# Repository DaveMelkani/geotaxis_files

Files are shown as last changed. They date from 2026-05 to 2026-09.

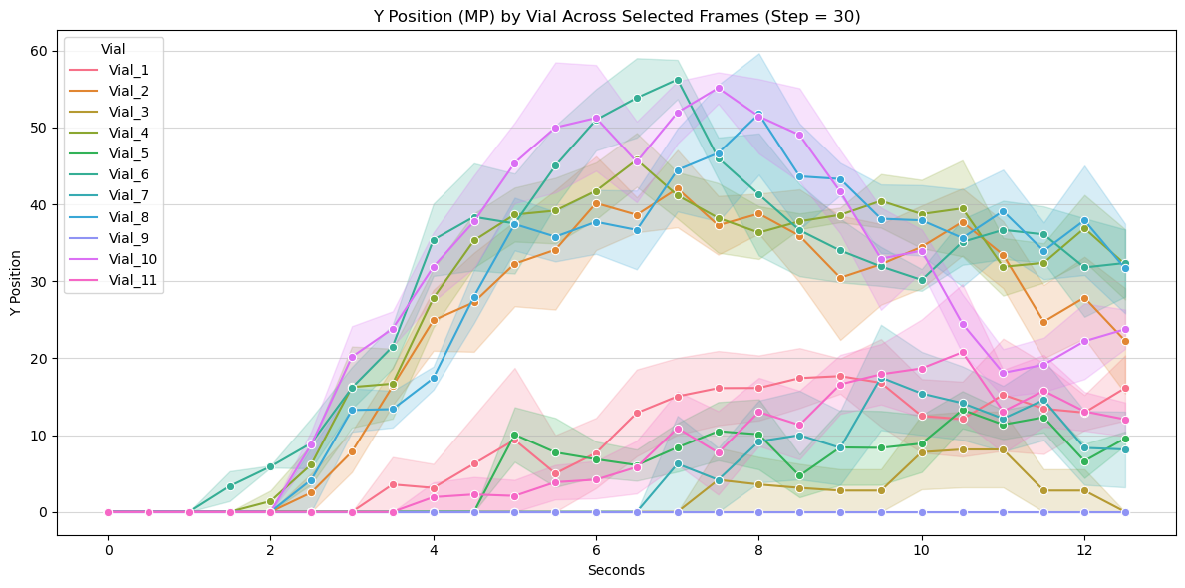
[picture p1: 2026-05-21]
Glaz_PolG_RNAi/Dev_Set2_GLAZ_POLG1_7wk_June_03_2025/percentage_MP_plot.png

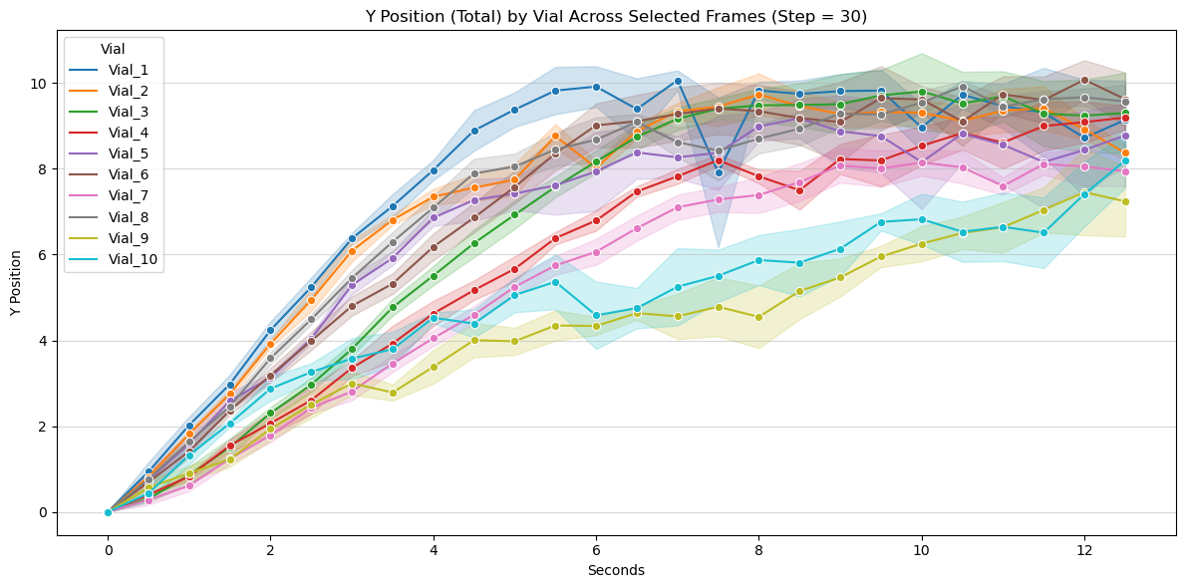
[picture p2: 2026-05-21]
Glaz_PolG_RNAi/Dev_Set2_GLAZ_POLG1_3wk_Jan_27_2024/position_Total_plot.png

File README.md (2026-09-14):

# Geotaxis Files

A hardware–software pipeline for fully automated, high-throughput negative geotaxis (climbing) assays in Drosophila melanogaster. The system pairs a 3D-printed, motorized 12-vial recording rig with an end-to-end Python/PyTorch analysis pipeline that converts raw video directly into time-resolved climbing metrics and statistical comparisons across genotypes, sexes, and ages, with no manual scoring or frame-by-frame human intervention required.

## System Overview & Purpose

Traditional negative geotaxis scoring requires a researcher to manually pause video at a fixed endpoint, draw a reference line, and tally the fraction of flies above it which is a process that is slow, low-resolution (a single data point per vial per trial), and subject to observer bias.

This pipeline replaces that workflow with continuous, population-level video tracking: raw H.264 recordings from the accompanying Raspberry Pi–based hardware rig are automatically converted, split into individual climbing trials, and analyzed frame-by-frame to extract climbing position, velocity, and zone occupancy for every vial, fully automatically, then statistically compared across user-specified genotype and age groups.

## Hardware 

The recording apparatus (STL files in main_stl_files_and_folders/) consists of:
- A custom 3D-printed 12-position vial holder and third-class-lever tapping mechanism, driven by a DC motor via an L298N motor driver module
- A Raspberry Pi 4B, controlling both the tapping motor (via GPIO) and video capture
- A Raspberry Pi HQ Camera (12.3 MP Sony IMX477 sensor) with a 6 mm CS-mount lens, recording at 60 fps, 1280×720
- A fixed lamp light source, positioned to eliminate glare and standardize illumination for background subtraction

A Python control script (run on the Pi) automatically executes four tap–climb cycles per recording: each cycle taps the vial rack (grounding the flies), then records a 15-second quiescent climbing window, for a total of four independent climbing trials per video file.

Full assembly instructions, GPIO pin assignments, and a complete bill of materials are provided in the manuscript's Supplementary Information.

## Core Features & Capabilities

**Vial detection**

- Custom-trained Faster R-CNN (ResNet-50 + Feature Pyramid Network) object detector, trained from scratch (no pretrained weights) on 1,140 annotated frames / 13,680 vial instances
- Inference filtered at confidence ≥ 0.85, with left-to-right spatial sorting of detected vials
- Achieves mean IoU > 0.95 against manual annotations on held-out validation frames

**Fly detection and zone classification**

- Per-pixel-max background subtraction (red-channel isolation) computed independently for each trimmed video
- Connected-component analysis to extract fly centroids per frame, filtered by area
- Each centroid assigned to a vial and classified into Low / Middle / High Performer (LP / MP / HP) vertical zones based on y-position, enabling continuous zone-occupancy tracking (not just an endpoint threshold)
- Population-level (not identity-preserving) tracking: all fly positions within a vial are averaged at each frame, avoiding identity-switching errors that arise from occlusion during climbing

**Video processing**

- Automated H.264 → MP4 conversion (ffmpeg, lossless quality settings)
- Automatic trial splitting into four 15-second clips via OpenCV MOG2 motion detection and SciPy peak/inactivity detection; no manual round definition required

**Statistical analysis**

- Linear Mixed-Effects (LME) models (Statsmodels, REML) with fixed effects for genotype, time, and their interaction, and random intercepts/slopes per vial to properly account for autocorrelated, repeated-measures data
- Harmonic Mean p-value (HMP) combination across correlated LME terms per genotype comparison
- Time-resolved Mann–Whitney U tests with BH-FDR corrections at each discrete timepoint, visualized as –log₁₀(q) significance heatmaps
- Peak-position summary bar plots with embedded significance annotations and replicate counts (N)

**Automation and batch processing**
- Iterates automatically over an arbitrary number of experiment/video subfolders
- Skips subfolders that have already been fully processed, enabling safe resumption of interrupted runs
- Aggregates results into sex-specific ("Output Males" / "Output Females") summary CSVs and plots across all processed videos

## Execution Pipeline Walkthrough

The pipeline runs in three sequential stages, orchestrated by MAIN_geotaxis.py (or interactively via gt_full_process.ipynb), and is also available as a standalone GUI executable for Windows, macOS, and Ubuntu Linux (no Python installation required).

### Stage 1: Recording

Assemble the hardware rig, load vials into the 12-position holder, and record via the on-device Python script. Each recording folder must contain the raw .h264 video and a geotaxis_metadata.csv file (columns: Vial_Num, Genotype, Sex, n), named identically to the video file. Recording folders are organized under a single top-level experiment directory (see Repository Structure below).

### Stage 2: Processing

For each unprocessed video subfolder, the pipeline automatically:
1. Converts the .h264 file to .mp4
2. Splits the video into four 15-second trimmed climbing trials via motion detection
3. Detects and spatially sorts vials with the Faster R-CNN model
4. Tracks fly centroids per frame and classifies them into LP/MP/HP zones
5. Subsamples to 2 Hz and converts pixel/frame units to centimeters/seconds
6. Writes per-trial CSVs and diagnostic plots

### Stage 3: Aggregation and Statistics

- Aggregates all per-trial outputs into wide-form, sex-specific summary tables (position, velocity, LP%, MP%, HP%) across replicates
- Computes climbing velocity as the numerical gradient of mean position over time
- Fits LME models and runs time-resolved Mann–Whitney U tests for a user-specified control genotype vs. one or more comparison genotypes, over a user-defined time window
- Outputs annotated trajectory plots, peak-position bar plots, and significance heatmaps

## Quantified Behavioral & Kinematic Metrics

| Metric | Unit | Description |
| --- | --- | --- |
| Position | cm | Mean climbing height across all tracked flies in a vial at each timepoint, calibrated from pixel coordinates via chamber height (17 cm / 720 px). |
| Velocity | cm/s | 	Instantaneous climbing speed, computed as the numerical gradient of mean position over time. |
| Low Performer (LP) | %  | Percentage of tracked flies in the lowest vertical zone of the vial at each timepoint. |
| Middle Performer (MP) | % | Percentage of tracked flies in the middle vertical zone at each timepoint. |
| High Performer (HP) | % | Percentage of tracked flies in the highest vertical zone at each timepoint. |
---

## Repository Structure
 
```
geotaxis_files/
├── MAIN_geotaxis.py            # Entry point for the full pipeline
├── gt_full_process.ipynb       # Interactive Jupyter notebook walkthrough
├── gt_process.py               # Core per-experiment processing logic
├── gt_data_agg.py              # Aggregation of processed data across experiments
├── statistical_analysis.py     # Mann-Whitney U tests and output generation
├── vial_network.py             # Vial detection/tracking network utilities
├── video_processor.py          # Frame extraction and fly position tracking
├── video_converter.py          # H.264 → MP4 conversion helper
├── file_installs.txt           # Required package list
├── main_stl_files_and_folders/ # 3D-printable hardware components
├── Glaz_PolG_RNAi/             # Experiment set: Glaz × PolG RNAi crosses
└── W1118_CLKOut/               # Experiment set: W1118 × CLK-out crosses
```

## File Formats

**Input:** .h264 video files (60 fps, 1280×720) with an accompanying geotaxis_metadata.csv per subfolder.

**Per-video output:** vial-position CSVs, per-trim fly-tracking CSVs, and diagnostic plots.

**Per-experiment output:** ten aggregated CSVs (5 metrics × 2 sexes), written to Output Males / Output Females subdirectories, plus PNG trajectory/bar/heatmap plots. All CSV outputs are compatible with GraphPad Prism, R, and Excel.

**Hardware:** 3D-printable .stl files for the vial holder, tapping arm, camera mount, and base frame (main_stl_files_and_folders/).

---

## Requirements

Python 3.8+ with: PyTorch (v2.3.1+cu121), torchvision, OpenCV, NumPy, Pandas, SciPy, Statsmodels, Matplotlib, Seaborn. NVIDIA CUDA 12.1 is recommended for vial detection but the pipeline automatically falls back to CPU execution if no compatible GPU is available. Standalone executables (no Python required) are available for Windows, macOS, and Ubuntu Linux.

## Citation

If you use this repository or platform in your research, please cite:

[1] Melkani D., Harnwal N., Desai S., Patel D., Melkani G. (year) Design and Implementation of an Automated Drosophila Locomotor Assay Using Computer Vision Tracking, submitted<br>

```
@article{Melkani2026Geotaxis,
  title     = {Design and Implementation of an Automated Drosophila Locomotor Assay Using Computer Vision Tracking},
  author    = {Melkani, Dave and Harnwal, Neelaksh and Desai, Shubhankar and Patel, Dev and Melkani, Girish C.},
  journal   = {Department of Pathology, University of Alabama at Birmingham},
  year      = {2026}
}
```

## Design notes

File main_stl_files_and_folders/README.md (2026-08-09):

# 3D-Printed Geotaxis Assay Device: STL File README

All STL files required to reproduce the device described in the associated manuscript are organized into the subfolders listed below. Print settings for each component are provided in the [Print Settings](#print-settings) section. Non-printed hardware requirements are listed in the [Bill of Materials](#bill-of-materials) section.

---

## Table of Contents

1. [Device Overview](#device-overview)
2. [How the Mechanism Works](#how-the-mechanism-works)
3. [File Structure](#file-structure)
4. [STL Files by Assembly](#stl-files-by-assembly)
   - [1. Curved Vial Holder](#1-curved-vial-holder)
   - [2. Arm / Middle Attachment](#2-arm--middle-attachment)
   - [3. Connecting Rod (Coupler)](#3-connecting-rod-coupler)
   - [4. Crank (Input Link)](#4-crank-input-link)
   - [5. Motor / Drive](#5-motor--drive)
   - [6. Base Frame](#6-base-frame)
   - [7. Cable Management Box](#7-cable-management-box)
5. [Assembly Order](#assembly-order)
6. [Print Settings](#print-settings)
7. [Bill of Materials](#bill-of-materials)

---

## Device Overview

This device automates the *Drosophila* geotaxis assay. It holds a set of fly vials in a curved arm, mechanically taps them to the bottom, and allows the flies to climb upward against gravity. A motorized crank-rocker mechanism converts continuous motor rotation into a repeating lift-and-tap oscillation of the vial arm at a consistent, user-controlled frequency.

The full mechanical system is 3D printed with the exception of two steel guide rods, bearings, screws, and the electric motor/gearbox unit.

---

## How the Mechanism Works

The device is a **crank-rocker four-bar linkage**. The key components and their roles are:

- **Base Frame** — The rigid black structure sitting on the bench, including two horizontal parallel steel rods. These rods connect the motor assembly to the pivot stand, keeping everything in alignment.
- **Motor & Gearbox** — An electric motor drives a 3D-printed gear pair to reduce rotational speed and increase torque.
- **Crank (Input Link)** — Attached directly to the gearbox output shaft. Rotates continuously in a full 360° circle.
- **Connecting Rod (Coupler)** — Links the crank's outer pin to the underside of the lever arm. An adjustable metal sleeve on this piece allows fine-tuning of the stroke length and resting height.
- **Lever Arm (Rocker)** — The long articulated arm spanning the top of the device. Pushed upward from below by the connecting rod and pinned at its right end to the fulcrum.
- **Pivot / Fulcrum** — The A-frame structure at the right end of the device. Houses a bearing and pin that act as the stationary hinge for the lever arm.
- **Vial Holder (End Effector)** — The curved vial holder at the left end of the lever arm. Swings upward when the crank pushes the arm, then drops back down to tap the flies to the bottom of the vials.

**Sequence of motion:**

1. The motor turns on, driving the gearbox and forcing the crank to rotate.
2. The crank's outer pin moves in a circle; the connecting rod transmits this motion upward.
3. The connecting rod pushes up on the mid-point of the lever arm.
4. Because the right end of the lever arm is fixed to the pivot point, the left end (carrying the vial holder) swings upward in an arc.
5. As the crank continues past the top of its rotation, it pulls the connecting rod down, which pulls the lever arm and vial holder back to the starting position, thus tapping the flies to the bottom.
6. This cycle repeats continuously at a frequency set by the motor speed.

---

## File Structure

```
main_files_and_folders_so_far/
├── curved_vial_holder/
│   ├── Curved_Vialholder.stl
│   ├── Curved_TopCover.stl
│   └── Gept_Arm_Backplate.stl
├── middle_parts_attach_holder/
│   ├── Vial_Holder_Connector.stl
│   ├── Piston_Push_Mid_link.stl
│   ├── Arm_Rotation_Bearing_Mount.stl
│   ├── Arm_Length_Body.stl
│   └── GeoT_Fulcram.stl
├── connecting_rod/
│   ├── Top_Bearing_TO_Cylinder_Connector.stl
│   ├── Top_Push_Cylinder.stl
│   └── Bottom_Bearing_Rod_Adapter(Piston).stl
├── crank_input_link/
│   ├── Crank_Hand.stl
│   ├── CrankStand_BottomBrace.stl
│   └── Crank_Stand.stl
├── motor_drive/
│   ├── Big_Motor_Faceplate.stl
│   ├── Big_motorSeat_brace.stl
│   ├── Big_motorSeat.stl
│   ├── Motor_Brace.stl
│   └── GeoT_gear_crank.stl
├── base_frame/
│   └── GeoT_Base_Fulcram_Mount.stl
│   └── GeoT_Base_Motor_Drive_Mount.stl
└── cable_management_box/
    ├── drivermount.stl
    └── drivermount_top.stl
```

---

## STL Files by Assembly

### 1. Curved Vial Holder
**Subfolder:** `curved_vial_holder/`

This is the end effector — the outermost component of the device. It holds the fly vials and is the part that swings upward and taps downward during the assay.

| File | Description |
|---|---|
| `Curved_Vialholder.stl` | Main curved arm with 12 vial slots arranged in a fan. **Print with supports.** |
| `Curved_TopCover.stl` | Cover that clips over the 12 vial openings to prevent vials from jumping out when the arm drops. |
| `Gept_Arm_Backplate.stl` | Backplate that bridges the vial holder to the arm sleeve (`Vial_Holder_Connector.stl`). Acts as the structural interface between the holder and the rest of the lever arm. |

---

### 2. Arm / Middle Attachment
**Subfolder:** `middle_parts_attach_holder/`

These parts form the lever arm — the long articulated arm that spans the top of the device. It is pinned at the right end (at the fulcrum) and free to swing at the left end where the vial holder attaches.

| File | Description |
|---|---|
| `Vial_Holder_Connector.stl` | Sleeve that fits over the lever arm body. Connects to `Gept_Arm_Backplate.stl` at one end and `Piston_Push_Mid-link.stl` at the other. |
| `Piston_Push_Mid-link.stl` | Central connector piece. Interfaces between the arm sleeve, the lever arm body, and the crank-rocker mechanism below. |
| `Arm_Rotation_Bearing_Mount.stl` | The body-end of the lever arm that connects to the fulcrum (`GeoT_Fulcram.stl`). |
| `Arm_Length_Body.stl` | Internal insert that provides stiffness, length and bearing surfaces at the pivot end of the arm. |
| `GeoT_Fulcram.stl` | The A-frame fulcrum stand on the right side of the device. This is the stationary anchor point — the lever arm rotates around a pin housed here. Two steel guide rods pass through its base to connect it rigidly to the motor assembly. |

---

### 3. Connecting Rod (Coupler)
**Subfolder:** `connecting_rod/`

The coupler link in the four-bar linkage. It transfers motion from the rotating crank up to the underside of the lever arm. The adjustable metal sleeve on this assembly (visible in the device photos) allows fine-tuning of stroke length and the arm's resting height.

| File | Description |
|---|---|
| `Top_Bearing_TO_Cylinder_Connector.stl` | Lower adapter that links the crank's outer pin to the connecting rod. |
| `Top_Push_Cylinder.stl` | Cylinder/slider portion of the connecting rod. Provides adjustability for stroke length. |
| `Bottom_Bearing_Rod_Adapter(Piston).stl` | Upper adapter that links the connecting rod to the underside of the lever arm. |

---

### 4. Crank (Input Link)
**Subfolder:** `crank_input_link/`

The crank is the input link that attaches directly to the gearbox output shaft and rotates continuously in 360°. Its outer pin drives the connecting rod, generating the oscillating motion of the lever arm.

| File | Description |
|---|---|
| `Crank_Hand.stl` | The rotating crank disk/arm attached to the gearbox output shaft. |
| `Crank_Stand.stl` | Stand that supports the crank by attaching to `Crank_Hand.stl`. |
| `CrankStand_BottomBrace.stl` | Brace that secures the `Crank_Hand.stl` to the `GeoT_Base_Motor_Drive_Mount.stl` . |

---

### 5. Motor / Drive
**Subfolder:** `motor_drive/`

These parts house and secure the motor/gearbox unit and carry the printed gear reduction stage between the motor shaft and the crank shaft.

| File | Description |
|---|---|
| `Big_Motor_Faceplate.stl` | Faceplate that secures the motor to its seat. |
| `Motor_Brace.stl` | Secondary brace that prevents the motor from rotating or shifting under load. |
| `GeoT_gear_crank.stl` | Printed gear pair (motor-side and crank-side gears). Reduces motor speed and increases torque at the crank shaft. **Print in PETG or ABS** rather than PLA for durability. |

---

### 6. Base Frame
**Subfolder:** `base_frame/`

The base provides the rigid ground link of the four-bar linkage. Two parallel steel rods slide through bores in the motor-side base block and the A-frame fulcrum stand, holding everything in alignment.

| File | Description |
|---|---|
| `GeoT_Base_Motor_Drive_Mount.stl` | Motor-side base block. Sits on the bench and anchors the motor assembly at one end of the two guide rods. |

> **Assembly note:** Slide all components onto the guide rods before tightening any set-screws. Square up the assembly first, then tighten.

---

### 7. Cable Management Box
**Subfolder:** `cable_management_box/`

A standalone enclosure for the motor driver electronics. This box sits separately on the bench near the device and is not mechanically connected to the device frame.

| File | Description |
|---|---|
| `drivermount.stl` | Main enclosure body for the motor driver board. Ventilated dot pattern on the face. |
| `drivermount_top.stl` | Lid for the driver enclosure. |

---

## Assembly Order

Assemble the device in the following order to avoid having to disassemble completed sections:

1. **Base frame** — Insert the two steel guide rods through `GeoT_Base_Motor_Drive_Mount.stl` and `GeoT_Base_Fulcram_Mount.stl`. Do not tighten set-screws yet.
2. **Motor / drive** — Seat the motor/gearbox into `Big_Motor_Faceplate.stl` and secure with `Motor_Brace.stl`. Mesh `GeoT_gear_crank.stl` with the motor pinion.
3. **Crank** — Attach `CrankStand_BottomBrace.stl` and `GeoT_Crank_Mount_motorEnd_Final.stl` to the gearbox output shaft. Mount `Crank_Hand.stl` and support with `Crank_Stand.stl`.
4. **Connecting rod** — Assemble `Top_Bearing_TO_Cylinder_Connector.stl`, `Top_Push_Cylinder.stl`, and `Bottom_Bearing_Rod_Adapter(Piston).stl`. Attach the lower end to the crank outer pin.
5. **Fulcrum / A-frame** — Slide `GeoT_Fulcram.stl` onto the free ends of the guide rods. Square to the motor assembly, then tighten all rod set-screws.
6. **Lever arm** — Assemble `Arm_Rotation_Bearing_Mount.stl` with `Arm_Length_Body.stl` and pin it to the fulcrum. Attach `Piston_Push_Mid-link.stl` and then `Vial_Holder_Connector.stl` working outward along the arm. Connect the upper end of the connecting rod to the arm underside via `Bottom_Bearing_Rod_Adapter(Piston).stl`.
7. **Vial holder** — Attach `Gept_Arm_Backplate.stl` to `Vial_Holder_Connector.stl`, then clip `Curved_Vialholder.stl` to the backplate. Fit `Curved_TopCover.stl` over the vial slots.
8. **Cable management** — Wire the motor driver into `drivermount.stl` and close with `drivermount_top.stl`. Place the box on the bench and connect motor leads.
9. **Final check** — Power on briefly and confirm the arm oscillates smoothly through its full arc before loading vials.

---

## Print Settings

| Component | Material | Layer Height | Wall Count | Infill | Supports |
|---|---|---|---|---|---|
| `Curved_Vialholder.stl` | PLA | 0.2 mm | 4 | 40% | **Yes** |
| `Curved_TopCover.stl` | PLA | 0.2 mm | 4 | 20% | **Yes** |
| `Gept_Arm_Backplate.stl` | PLA | 0.2 mm | 4 | 40% | No |
| `Vial_Holder_Connector.stl` | PLA | 0.2 mm | 6 | 40% | No |
| `Piston_Push_Mid-link.stl` | PLA | 0.2 mm | 6 | 40% | **Yes** |
| `Arm_Rotation_Bearing_Mount.stl` | PLA | 0.2 mm | 6 | 40% | No |
| `Arm_Length_Body.stl` | PLA | 0.2 mm | 4 | 60% | No |
| `GeoT_Fulcram.stl` | PLA | 0.2 mm | 4 | 60% | No — print upright so layer lines run parallel to load |
| `Top_Bearing_TO_Cylinder_Connector.stl` | PLA | 0.2 mm | 4 | 60% | No |
| `Top_Push_Cylinder.stl` | PLA | 0.2 mm | 4 | 60% | No |
| `Bottom_Bearing_Rod_Adapter(Piston).stl` | PLA | 0.2 mm | 4 | 60% | No |
| `Crank_Hand.stl` | PLA | 0.2 mm | 4 | 60% | **Yes** — print on its side |
| `CrankStand_BottomBrace.stl` | PLA | 0.2 mm | 6 | 40% | No |
| `Big_Motor_Faceplate.stl` | PLA | 0.2 mm | 4 | 40% | No |
| `Big_motorSeat.stl` | PLA | 0.2 mm | 4 | 40% | No |
| `Big_motorSeat_brace.stl` | PLA | 0.2 mm | 4 | 40% | No |
| `Motor_Brace.stl` | PLA | 0.2 mm | 4 | 40% | No |
| `GeoT_gear_crank.stl` | **PETG or ABS** | 0.15 mm | 8 | 60% | No |
| `GeoT_Base_Fulcram_Mount.stl` | PLA | 0.2 mm | 6 | 40% | No |
| `GeoT_Base_Motor_Drive_Mount.stl` | PLA | 0.2 mm | 6 | 40% | No |
| `drivermount.stl` | PLA | 0.2 mm | 2 | 20% | No |
| `drivermount_top.stl` | PLA | 0.2 mm | 2 | 20% | No |

> **Note on gears:** `GeoT_gear_crank.stl` should be printed in PETG or ABS at a finer layer height (0.15 mm) for better dimensional accuracy and wear resistance. PLA gears will work initially but may wear quickly under continuous use.

> **Note on orientation:** Print `GeoT_Fulcram.stl` and `Crank_Stand.stl` upright (standing on their base) so that layer lines run parallel to the primary load direction, maximizing inter-layer strength at the stress points.

---

## Bill of Materials

Non-printed hardware required for assembly:

| Item | Qty | Notes |
|---|---|---|
| Steel guide rods | 2 | Diameter must match bores in `GeoT_Base_Motor_Drive_Mount.stl` and `GeoT_Fulcram.stl` |
| Bearings | 2+ | At the pivot/fulcrum point and crank shaft ends |
| DC gear motor | 1 | The motor and gearbox unit visible in device photos |
| Motor driver board | 1 | Housed in `drivermount.stl` enclosure |
| M3/M4 screws and nuts | Assorted | For scuring all printed-to-printed and printed-to-hardware interfaces |
| Set-screws | 4+ | For locking guide rods in base and fulcrum blocks |
| Hinge pin | 1 | Passes through bearing in `GeoT_Fulcram.stl` to pin the lever arm |
| Crank outer pin | 1 | Connects `Crank_Hand.stl` to `Top_Bearing_TO_Cylinder_Connector.stl` |
| Metal adjustable clamp/sleeve | 1 | On the connecting rod; used to fine-tune stroke length and resting height |

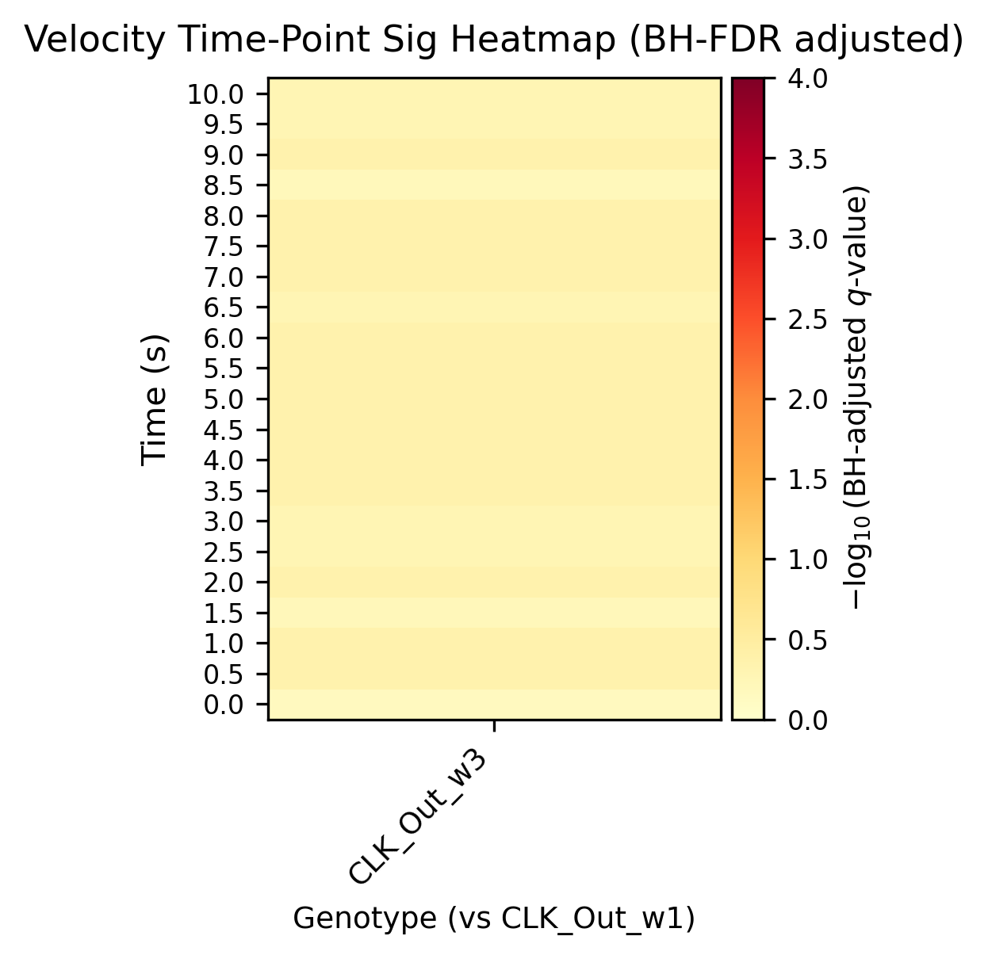
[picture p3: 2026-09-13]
W1118_CLKOut/_Output_Males/male_stats_control_CLK_Out_w1_1/male_mannwhitney_heatmap_velocity_control_CLK_Out_w1.tiff

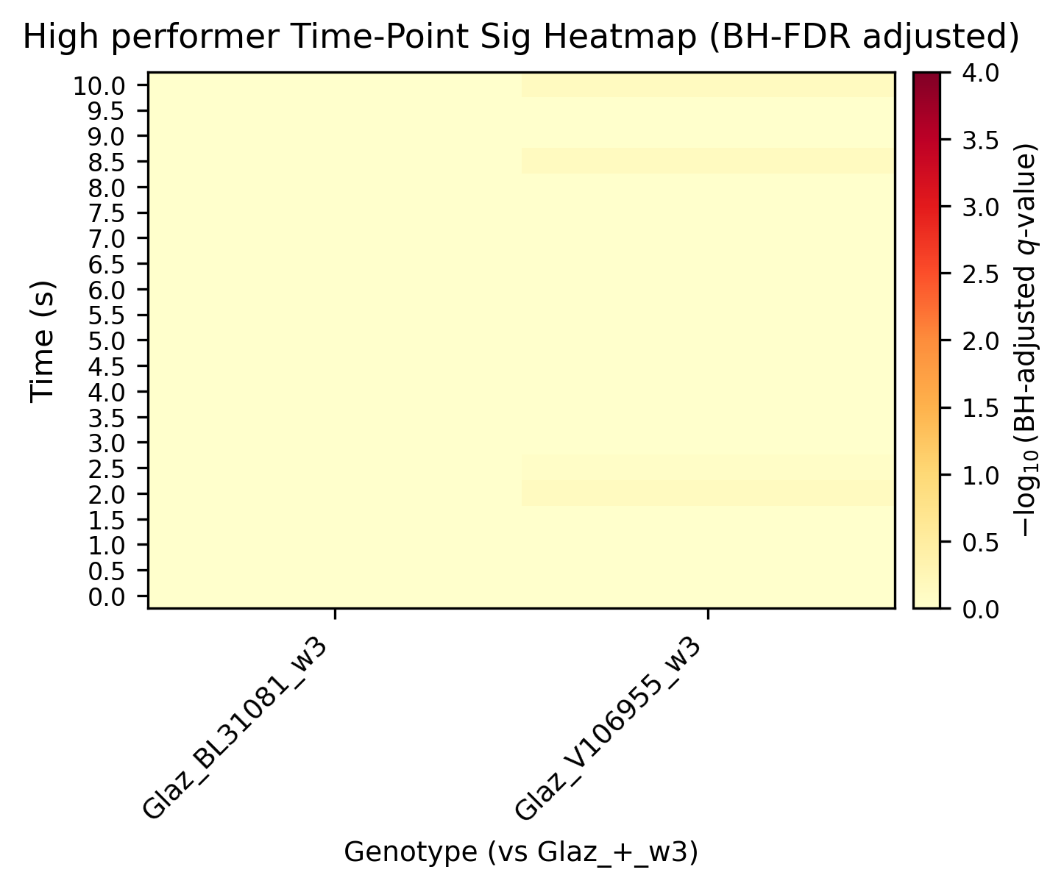
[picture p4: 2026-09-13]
Glaz_PolG_RNAi/_Output_Males/male_stats_control_Glaz_+_w3_1/male_mannwhitney_heatmap_high performer_control_Glaz_+_w3.tiff

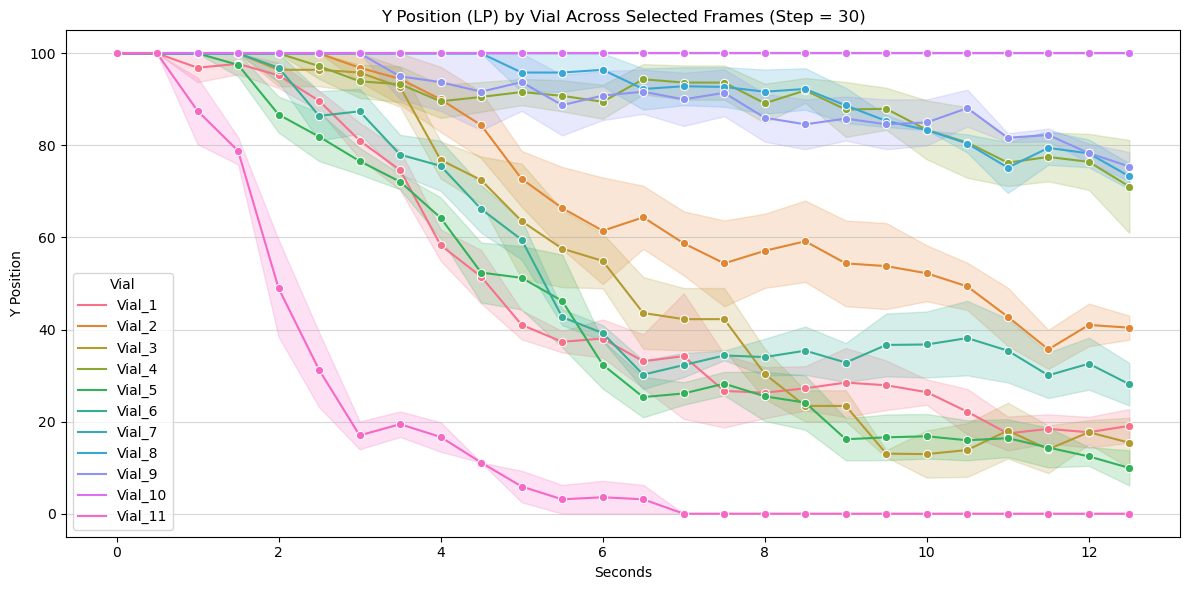
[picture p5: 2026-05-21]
Glaz_PolG_RNAi/Dev_Set1_GLAZ_POLG1_7wk_Feb_12_2025/percentage_LP_plot.png

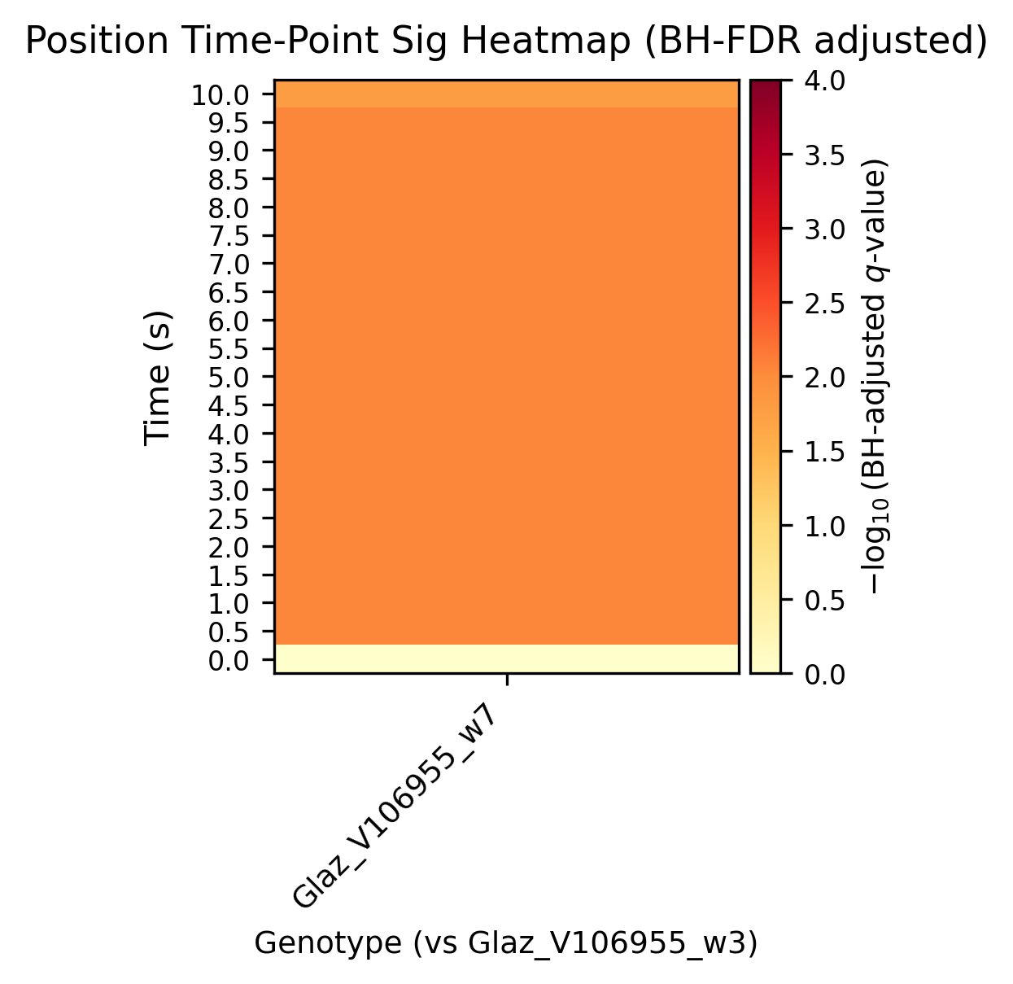
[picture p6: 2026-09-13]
Glaz_PolG_RNAi/_Output_Males/male_stats_control_Glaz_V106955_w3_1/male_mannwhitney_heatmap_position_control_Glaz_V106955_w3.tiff

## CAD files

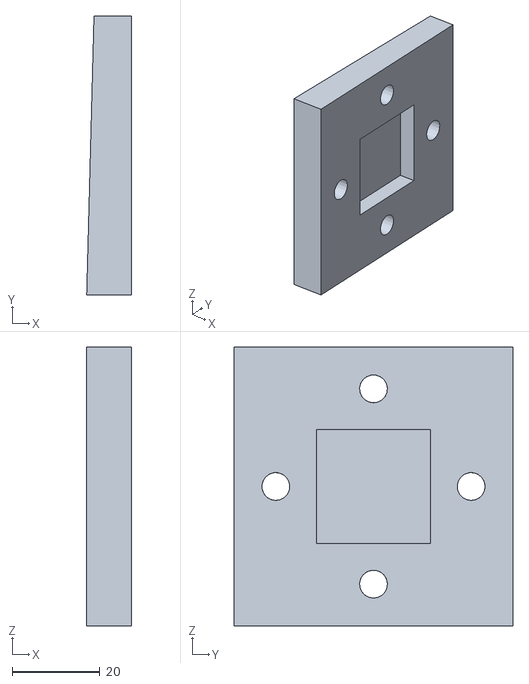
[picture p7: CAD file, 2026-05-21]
main_stl_files_and_folders/1_curved_vial_holder/Gept_Arm_Backplate.stl
10.2 x 63.5 x 63.5

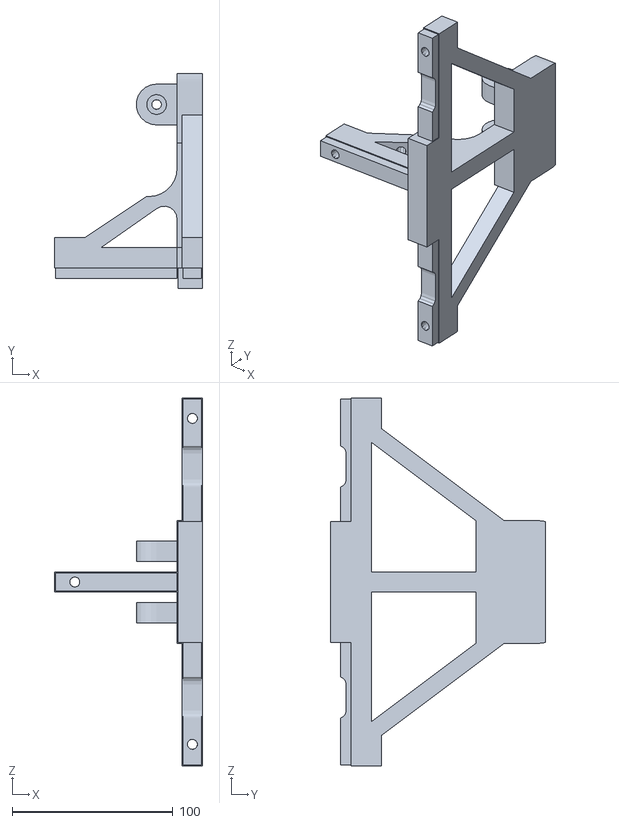
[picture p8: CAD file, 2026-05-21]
main_stl_files_and_folders/2_middle_parts_attach_holder_pivot_fulcrum/GeoT_Fulcram.stl
92.1 x 133.6 x 228.6

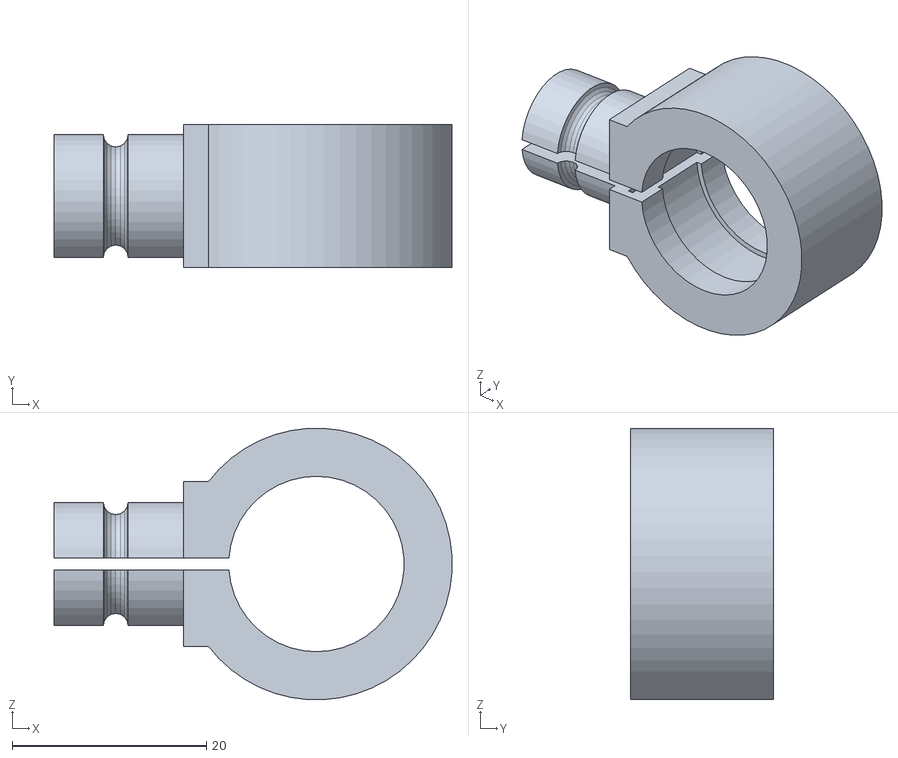
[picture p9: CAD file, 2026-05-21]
main_stl_files_and_folders/3_connecting_rod/Top_Bearing_TO_Cylinder_Connector.stl
40.9 x 14.7 x 27.9

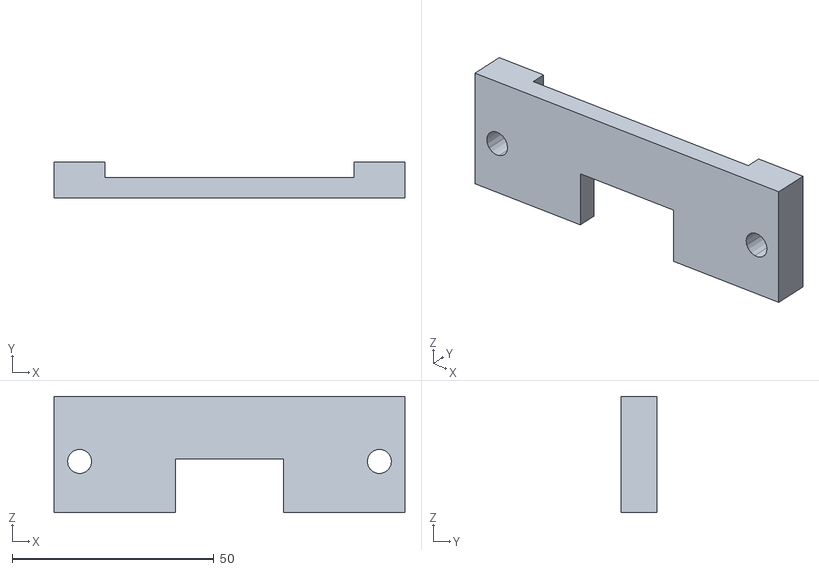
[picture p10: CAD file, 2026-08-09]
main_stl_files_and_folders/4_crank_input_link/CrankStand_BottomBrace.stl
87.0 x 8.89 x 28.8

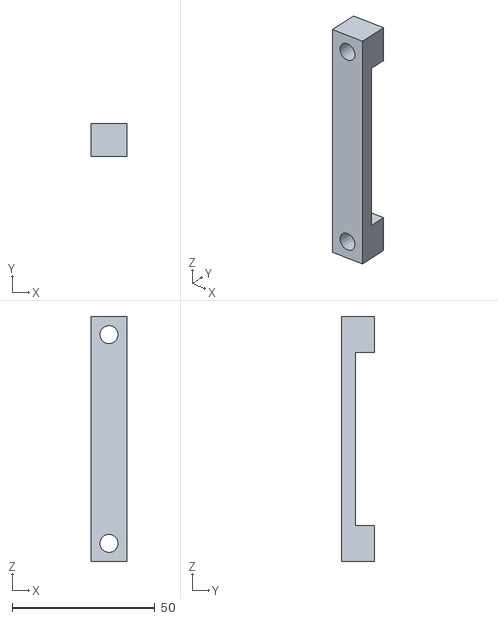
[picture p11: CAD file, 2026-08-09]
main_stl_files_and_folders/5_motor_drive/Big_motorSeat_brace.stl
12.7 x 11.4 x 85.7

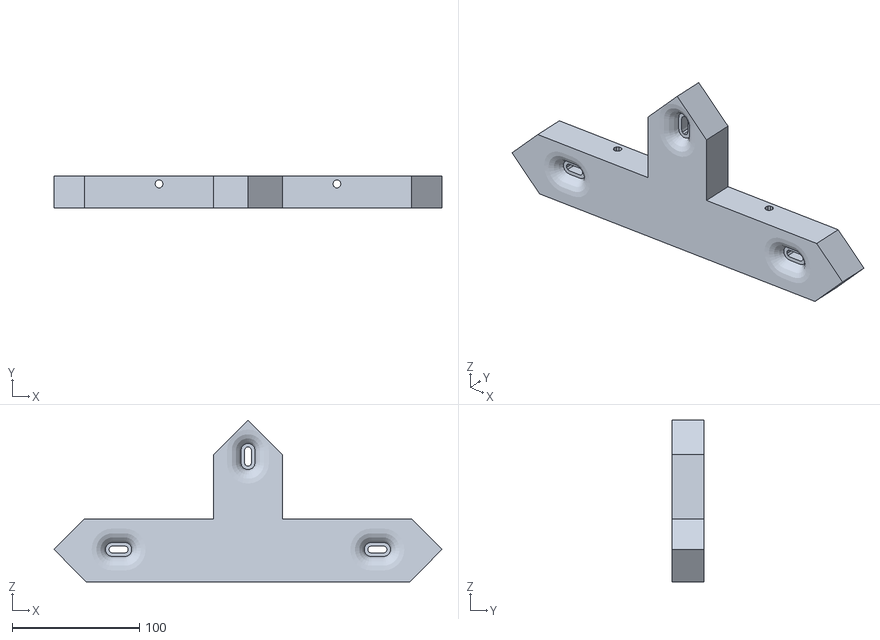
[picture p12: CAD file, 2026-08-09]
main_stl_files_and_folders/6_base_frame/GeoT_Base_Fulcram_Mount.stl
304.8 x 25.4 x 127.0

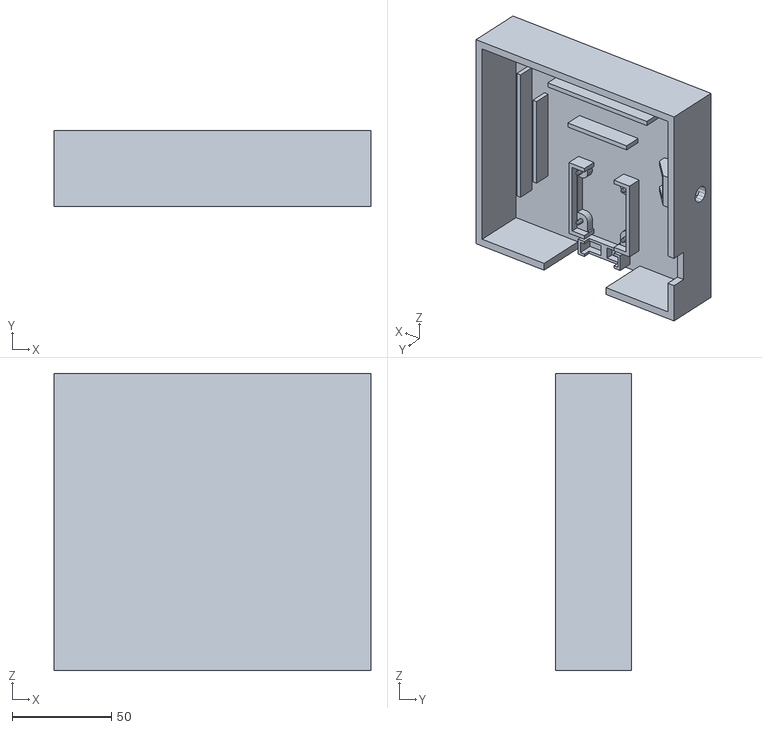
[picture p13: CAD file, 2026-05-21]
main_stl_files_and_folders/7_cable_management_box/drivermount.stl
160.0 x 38.2 x 150.0

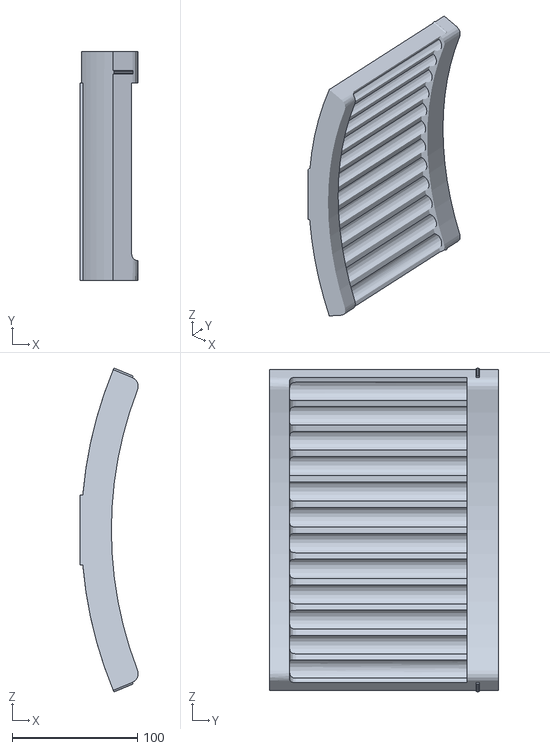
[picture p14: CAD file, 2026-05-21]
main_stl_files_and_folders/1_curved_vial_holder/Curved_Vialholder.stl
46.6 x 182.5 x 258.2

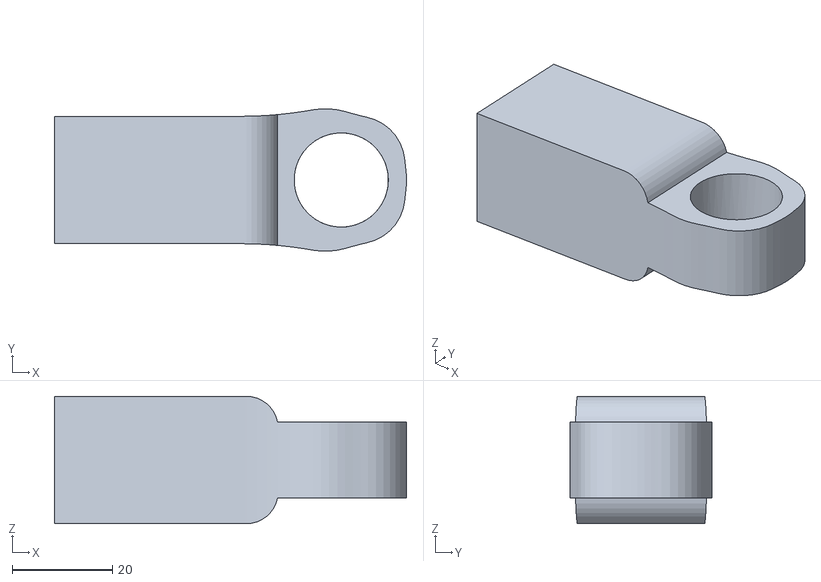
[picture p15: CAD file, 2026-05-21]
main_stl_files_and_folders/2_middle_parts_attach_holder_pivot_fulcrum/Arm_Rotation_Bearing_Mount.stl
70.2 x 28.4 x 25.4

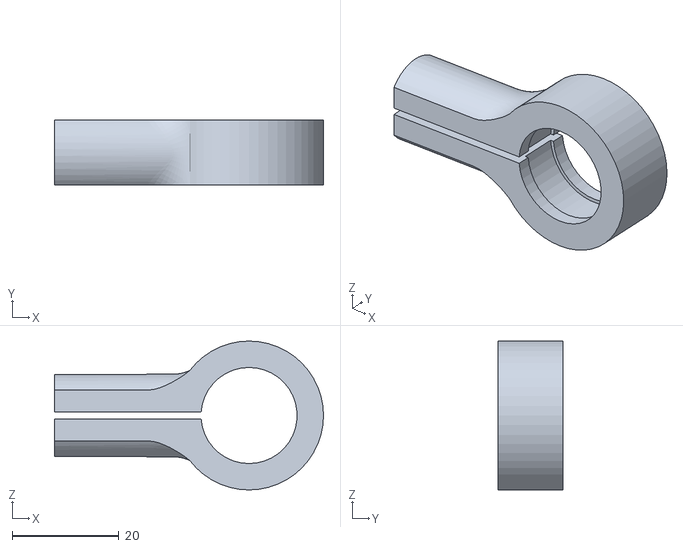
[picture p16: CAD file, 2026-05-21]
main_stl_files_and_folders/3_connecting_rod/Bottom_Bearing_Rod_Adapter(Piston).stl
50.5 x 12.2 x 27.9

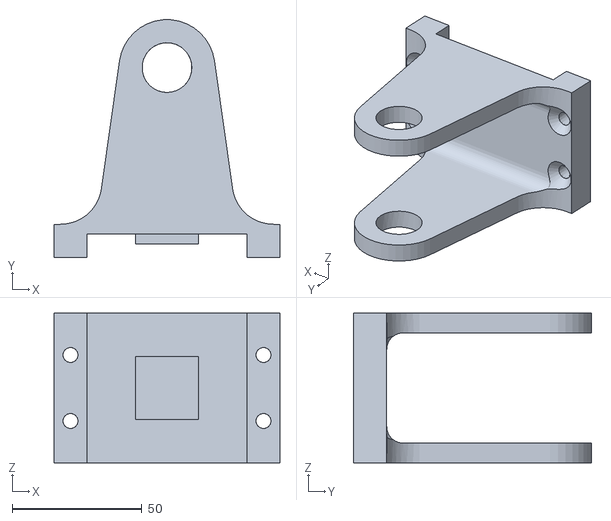
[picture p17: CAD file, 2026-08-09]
main_stl_files_and_folders/4_crank_input_link/Crank_Stand.stl
87.0 x 91.4 x 57.7

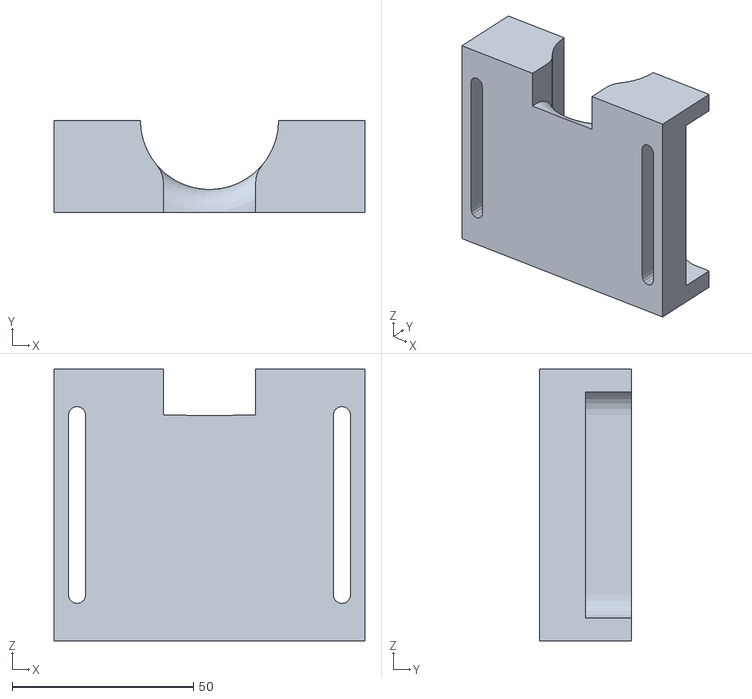
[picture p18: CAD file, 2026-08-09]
main_stl_files_and_folders/5_motor_drive/Big_motorSeat.stl
85.7 x 25.4 x 74.9

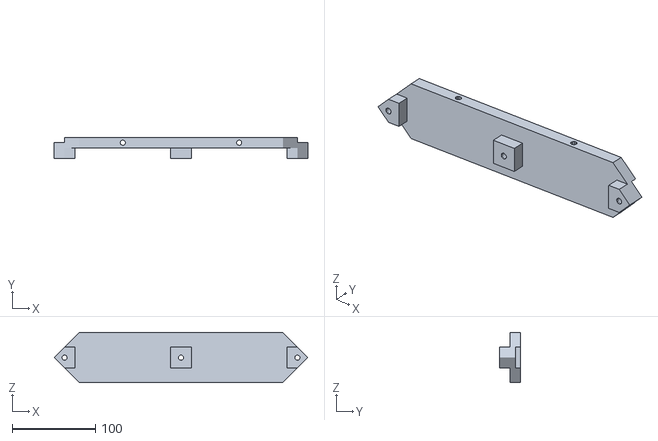
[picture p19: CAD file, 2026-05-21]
main_stl_files_and_folders/6_base_frame/GeoT_Base_Motor_Drive_Mount.stl
304.8 x 25.4 x 60.3

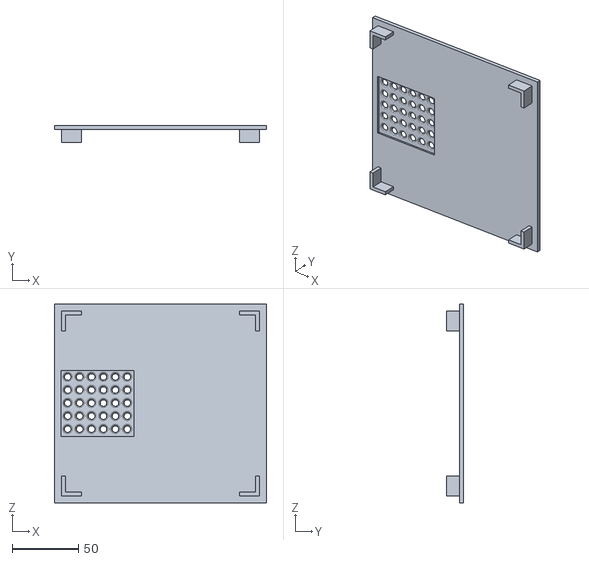
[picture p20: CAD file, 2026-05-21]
main_stl_files_and_folders/7_cable_management_box/drivermount_top.stl
160.0 x 13.2 x 150.0

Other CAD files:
main_stl_files_and_folders/1_curved_vial_holder/Curved_TopCover.stl
main_stl_files_and_folders/2_middle_parts_attach_holder_pivot_fulcrum/Piston_Push_Mid-link.stl
main_stl_files_and_folders/3_connecting_rod/Top_Push_Cylinder.stl
main_stl_files_and_folders/4_crank_input_link/Crank_Hand.stl
main_stl_files_and_folders/2_middle_parts_attach_holder_pivot_fulcrum/Arm_Length_Body.stl
main_stl_files_and_folders/2_middle_parts_attach_holder_pivot_fulcrum/Vial_Holder_Connector.stl
main_stl_files_and_folders/5_motor_drive/Big_Motor_Faceplate.stl
main_stl_files_and_folders/5_motor_drive/GeoT_gear_crank.stl
main_stl_files_and_folders/5_motor_drive/Motor_Brace.stl

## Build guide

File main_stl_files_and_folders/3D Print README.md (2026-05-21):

# 3D-Printed Geotaxis Assay Device — STL File README

All STL files required to reproduce the device described in the associated manuscript are organized into the subfolders listed below. Print settings for each component are provided in the [Print Settings](#print-settings) section. Non-printed hardware requirements are listed in the [Bill of Materials](#bill-of-materials) section.

---

## Table of Contents

1. [Device Overview](#device-overview)
2. [How the Mechanism Works](#how-the-mechanism-works)
3. [File Structure](#file-structure)
4. [STL Files by Assembly](#stl-files-by-assembly)
   - [1. Curved Vial Holder](#1-curved-vial-holder)
   - [2. Arm / Middle Attachment](#2-arm--middle-attachment)
   - [3. Connecting Rod (Coupler)](#3-connecting-rod-coupler)
   - [4. Crank (Input Link)](#4-crank-input-link)
   - [5. Motor / Drive](#5-motor--drive)
   - [6. Base Frame](#6-base-frame)
   - [7. Cable Management Box](#7-cable-management-box)
5. [Assembly Order](#assembly-order)
6. [Print Settings](#print-settings)
7. [Bill of Materials](#bill-of-materials)

---

## Device Overview

This device automates the *Drosophila* geotaxis assay. It holds a set of fly vials in a curved arm, mechanically taps them to the bottom, and allows the flies to climb upward against gravity. A motorized crank-rocker mechanism converts continuous motor rotation into a repeating lift-and-tap oscillation of the vial arm at a consistent, user-controlled frequency.

The full mechanical system is 3D printed with the exception of two steel guide rods, bearings, screws, and the electric motor/gearbox unit.

---

## How the Mechanism Works

The device is a **crank-rocker four-bar linkage**. The key components and their roles are:

- **Base Frame** — The rigid black structure sitting on the bench, including two horizontal parallel steel rods. These rods connect the motor assembly to the pivot stand, keeping everything in alignment.
- **Motor & Gearbox** — An electric motor drives a printed gear pair to reduce rotational speed and increase torque.
- **Crank (Input Link)** — Attached directly to the gearbox output shaft. Rotates continuously in a full 360° circle.
- **Connecting Rod (Coupler)** — Links the crank's outer pin to the underside of the lever arm. An adjustable metal sleeve on this piece allows fine-tuning of the stroke length and resting height.
- **Lever Arm (Rocker)** — The long articulated arm spanning the top of the device. Pushed upward from below by the connecting rod and pinned at its right end to the fulcrum.
- **Pivot / Fulcrum** — The A-frame structure at the right end of the device. Houses a bearing and pin that act as the stationary hinge for the lever arm.
- **Vial Holder (End Effector)** — The curved vial holder at the left end of the lever arm. Swings upward when the crank pushes the arm, then drops back down to tap the flies to the bottom of the vials.

**Sequence of motion:**

1. The motor turns on, driving the gearbox and forcing the crank to rotate.
2. The crank's outer pin moves in a circle; the connecting rod transmits this motion upward.
3. The connecting rod pushes up on the mid-point of the lever arm.
4. Because the right end of the lever arm is fixed to the pivot point, the left end (carrying the vial holder) swings upward in an arc.
5. As the crank continues past the top of its rotation, it pulls the connecting rod down, which pulls the lever arm and vial holder back to the starting position — tapping the flies to the bottom.
6. This cycle repeats continuously at a frequency set by the motor speed.

---

## File Structure

```
main_files_and_folders_so_far/
├── curved_vial_holder/
│   ├── Curved_Vialholder.stl
│   ├── Curved_TopCover.stl
│   └── Gept_Arm_Backplate.stl
├── middle_parts_attach_holder/
│   ├── ArmSleve.stl
│   ├── CentrPS.stl
│   ├── ARM_B_end_d2.stl
│   ├── ArmInsert2.stl
│   └── GeoT_Fulcram.stl
├── connecting_rod/
│   ├── Bearing_Rod_PistonAdapter.stl
│   ├── Bearing_Rod_Piston_Cyl.stl
│   └── Bearing_Rod_Adapter.stl
├── crank_input_link/
│   ├── cranckside_D5.stl
│   ├── GeoT_Crank_Mount_final.stl
│   ├── GeoT_Crank_Mount_motorEnd_Final.stl
│   └── ND_CrankStand.stl
├── motor_drive/
│   ├── Big_Motor_Faceplate.stl
│   ├── Motor_Brace.stl
│   └── GeoT_gear_crank.stl
├── base_frame/
│   └── GeoT_Base_motor_D2.stl
└── cable_management_box/
    ├── drivermount.stl
    └── drivermount_top.stl
```

---

## STL Files by Assembly

### 1. Curved Vial Holder
**Subfolder:** `curved_vial_holder/`

This is the end effector — the outermost component of the device. It holds the fly vials and is the part that swings upward and taps downward during the assay.

| File | Description |
|---|---|
| `Curved_Vialholder.stl` | Main curved arm with 12 vial slots arranged in a fan. **Print with supports.** |
| `Curved_TopCover.stl` | Cover that clips over the 12 vial openings to prevent vials from jumping out when the arm drops. |
| `Gept_Arm_Backplate.stl` | Backplate that bridges the vial holder to the arm sleeve (`ArmSleve.stl`). Acts as the structural interface between the holder and the rest of the lever arm. |

---

### 2. Arm / Middle Attachment
**Subfolder:** `middle_parts_attach_holder/`

These parts form the lever arm — the long articulated arm that spans the top of the device. It is pinned at the right end (at the fulcrum) and free to swing at the left end where the vial holder attaches.

| File | Description |
|---|---|
| `ArmSleve.stl` | Sleeve that fits over the lever arm body. Connects to `Gept_Arm_Backplate.stl` at one end and `CentrPS.stl` at the other. |
| `CentrPS.stl` | Central connector piece. Interfaces between the arm sleeve, the lever arm body, and the crank-rocker mechanism below. |
| `ARM_B_end_d2.stl` | The body-end of the lever arm that connects to the fulcrum (`GeoT_Fulcram.stl`). |
| `ArmInsert2.stl` | Internal insert that provides stiffness and bearing surfaces at the pivot end of the arm. |
| `GeoT_Fulcram.stl` | The A-frame fulcrum stand on the right side of the device. This is the stationary anchor point — the lever arm rotates around a pin housed here. Two steel guide rods pass through its base to connect it rigidly to the motor assembly. |

---

### 3. Connecting Rod (Coupler)
**Subfolder:** `connecting_rod/`

The coupler link in the four-bar linkage. It transfers motion from the rotating crank up to the underside of the lever arm. The adjustable metal sleeve on this assembly (visible in the device photos) allows fine-tuning of stroke length and the arm's resting height.

| File | Description |
|---|---|
| `Bearing_Rod_PistonAdapter.stl` | Lower adapter that links the crank's outer pin to the connecting rod. |
| `Bearing_Rod_Piston_Cyl.stl` | Cylinder/slider portion of the connecting rod. Provides adjustability for stroke length. |
| `Bearing_Rod_Adapter.stl` | Upper adapter that links the connecting rod to the underside of the lever arm. |

---

### 4. Crank (Input Link)
**Subfolder:** `crank_input_link/`

The crank is the input link that attaches directly to the gearbox output shaft and rotates continuously in 360°. Its outer pin drives the connecting rod, generating the oscillating motion of the lever arm.

| File | Description |
|---|---|
| `cranckside_D5.stl` | The rotating crank disk/arm attached to the gearbox output shaft. |
| `GeoT_Crank_Mount_final.stl` | Mount that secures the crank to the gearbox on the crank side. |
| `GeoT_Crank_Mount_motorEnd_Final.stl` | Mount for the motor end of the crank shaft. |
| `ND_CrankStand.stl` | Stand that supports the crank by attaching to `cranckside_D5.stl`. |

---

### 5. Motor / Drive
**Subfolder:** `motor_drive/`

These parts house and secure the motor/gearbox unit and carry the printed gear reduction stage between the motor shaft and the crank shaft.

| File | Description |
|---|---|
| `Big_Motor_Faceplate.stl` | Faceplate that secures the motor to its seat. |
| `Motor_Brace.stl` | Secondary brace that prevents the motor from rotating or shifting under load. |
| `GeoT_gear_crank.stl` | Printed gear pair (motor-side and crank-side gears). Reduces motor speed and increases torque at the crank shaft. **Print in PETG or ABS** rather than PLA for durability. |

---

### 6. Base Frame
**Subfolder:** `base_frame/`

The base provides the rigid ground link of the four-bar linkage. Two parallel steel rods slide through bores in the motor-side base block and the A-frame fulcrum stand, holding everything in alignment.

| File | Description |
|---|---|
| `GeoT_Base_motor_D2.stl` | Motor-side base block. Sits on the bench and anchors the motor assembly at one end of the two guide rods. |

> **Assembly note:** Slide all components onto the guide rods before tightening any set-screws. Square up the assembly first, then tighten.

---

### 7. Cable Management Box
**Subfolder:** `cable_management_box/`

A standalone enclosure for the motor driver electronics. This box sits separately on the bench near the device and is not mechanically connected to the device frame.

| File | Description |
|---|---|
| `drivermount.stl` | Main enclosure body for the motor driver board. Ventilated dot pattern on the face. |
| `drivermount_top.stl` | Lid for the driver enclosure. |

---

## Assembly Order

Assemble the device in the following order to avoid having to disassemble completed sections:

1. **Base frame** — Insert the two steel guide rods through `GeoT_Base_motor_D2.stl`. Do not tighten set-screws yet.
2. **Motor / drive** — Seat the motor/gearbox into `Big_Motor_Faceplate.stl` and secure with `Motor_Brace.stl`. Mesh `GeoT_gear_crank.stl` with the motor pinion.
3. **Crank** — Attach `GeoT_Crank_Mount_final.stl` and `GeoT_Crank_Mount_motorEnd_Final.stl` to the gearbox output shaft. Mount `cranckside_D5.stl` and support with `ND_CrankStand.stl`.
4. **Connecting rod** — Assemble `Bearing_Rod_PistonAdapter.stl`, `Bearing_Rod_Piston_Cyl.stl`, and `Bearing_Rod_Adapter.stl`. Attach the lower end to the crank outer pin.
5. **Fulcrum / A-frame** — Slide `GeoT_Fulcram.stl` onto the free ends of the guide rods. Square to the motor assembly, then tighten all rod set-screws.
6. **Lever arm** — Assemble `ARM_B_end_d2.stl` with `ArmInsert2.stl` and pin it to the fulcrum. Attach `CentrPS.stl` and then `ArmSleve.stl` working outward along the arm. Connect the upper end of the connecting rod to the arm underside via `Bearing_Rod_Adapter.stl`.
7. **Vial holder** — Attach `Gept_Arm_Backplate.stl` to `ArmSleve.stl`, then clip `Curved_Vialholder.stl` to the backplate. Fit `Curved_TopCover.stl` over the vial slots.
8. **Cable management** — Wire the motor driver into `drivermount.stl` and close with `drivermount_top.stl`. Place the box on the bench and connect motor leads.
9. **Final check** — Power on briefly and confirm the arm oscillates smoothly through its full arc before loading vials.

---

## Print Settings

| Component | Material | Layer Height | Infill | Supports |
|---|---|---|---|---|
| `Curved_Vialholder.stl` | PLA | 0.2 mm | 40% | **Yes** |
| `Curved_TopCover.stl` | PLA | 0.2 mm | 20% | **Yes** |
| `Gept_Arm_Backplate.stl` | PLA | 0.2 mm | 40% | No |
| `ArmSleve.stl` | PLA | 0.2 mm | 40% | No |
| `CentrPS.stl` | PLA | 0.2 mm | 40% | No |
| `ARM_B_end_d2.stl` | PLA | 0.2 mm | 40% | No |
| `ArmInsert2.stl` | PLA | 0.2 mm | 60% | No |
| `GeoT_Fulcram.stl` | PLA | 0.2 mm | 60% | No — print upright so layer lines run parallel to load |
| `Bearing_Rod_PistonAdapter.stl` | PLA | 0.2 mm | 60% | No |
| `Bearing_Rod_Piston_Cyl.stl` | PLA | 0.2 mm | 60% | No |
| `Bearing_Rod_Adapter.stl` | PLA | 0.2 mm | 60% | No |
| `cranckside_D5.stl` | PLA | 0.2 mm | 60% | No |
| `GeoT_Crank_Mount_final.stl` | PLA | 0.2 mm | 40% | No |
| `GeoT_Crank_Mount_motorEnd_Final.stl` | PLA | 0.2 mm | 40% | No |
| `ND_CrankStand.stl` | PLA | 0.2 mm | 60% | No — print upright |
| `Big_Motor_Faceplate.stl` | PLA | 0.2 mm | 40% | No |
| `Motor_Brace.stl` | PLA | 0.2 mm | 40% | No |
| `GeoT_gear_crank.stl` | **PETG or ABS** | 0.15 mm | 60% | No |
| `GeoT_Base_motor_D2.stl` | PLA | 0.2 mm | 40% | No |
| `drivermount.stl` | PLA | 0.2 mm | 20% | No |
| `drivermount_top.stl` | PLA | 0.2 mm | 20% | No |

> **Note on gears:** `GeoT_gear_crank.stl` should be printed in PETG or ABS at a finer layer height (0.15 mm) for better dimensional accuracy and wear resistance. PLA gears will work initially but may wear quickly under continuous use.

> **Note on orientation:** Print `GeoT_Fulcram.stl` and `ND_CrankStand.stl` upright (standing on their base) so that layer lines run parallel to the primary load direction, maximizing inter-layer strength at the stress points.

---

## Bill of Materials

Non-printed hardware required for assembly:

| Item | Qty | Notes |
|---|---|---|
| Steel guide rods | 2 | Diameter must match bores in `GeoT_Base_motor_D2.stl` and `GeoT_Fulcram.stl` |
| Bearings | 2+ | At the pivot/fulcrum point and crank shaft ends |
| DC gear motor | 1 | The motor and gearbox unit visible in device photos |
| Motor driver board | 1 | Housed in `drivermount.stl` enclosure |
| M3/M4 screws and nuts | Assorted | For securing all printed-to-printed and printed-to-hardware interfaces |
| Set-screws | 4+ | For locking guide rods in base and fulcrum blocks |
| Hinge pin | 1 | Passes through bearing in `GeoT_Fulcram.stl` to pin the lever arm |
| Crank outer pin | 1 | Connects `cranckside_D5.stl` to `Bearing_Rod_PistonAdapter.stl` |
| Metal adjustable clamp/sleeve | 1 | On the connecting rod; used to fine-tune stroke length and resting height |

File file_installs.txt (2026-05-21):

WindowsOS Install Steps:
# Do this one time:
conda env remove -n geo_env -y
conda create -n geo_env -c conda-forge python=3.10 nomkl ffmpeg pandas numpy scipy matplotlib scikit-learn scikit-image pillow tqdm seaborn statsmodels -y
conda activate geo_env
pip install opencv-python-headless
pip install torch torchvision torchaudio

# Do this every time:
conda activate geo_env
python MAIN_geotaxis.py

# Ubuntu LinuxOS Install Steps:
# Do this one time:
module load Anaconda3
conda create -n geo_env
conda activate geo_env
pip3 install torch torchvision torchaudio opencv-python
conda install -c conda-forge ffmpeg

# Do this every time:
conda activate geo_env
python MAIN_geotaxis.py

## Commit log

2026-05-18 initial push
    initial push
    [female_agg_high-performer_data.csv, female_agg_low-performer_data.csv, female_agg_middle-performer_data.csv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]
2026-05-21 adding stl folders & readme
    adding stl folders & readme
    [ARM_B_end_d2.stl, ArmInsert2.stl, ArmSleve.stl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]
2026-05-21 Rename 3D Print README.md to README.md
2026-05-21 new pushes
    new pushes
    [female_stats_mannwhitney_high performer_control_W1118_w1.csv, female_stats_mannwhitney_low performer_control_W1118_w1.csv, female_stats_mannwhitney_middle perf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]
2026-05-21 glaz push
    glaz push
    [aggregated_female_all_cycles.csv, aggregated_male_all_cycles.csv, female_agg_high-performer_data.csv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]
2026-07-29 updated 3d print readme.md
    updated 3d print readme.md
    [Arm_Length_Body.stl, Arm_Rotation_Bearing_Mount.stl, Bottom_Bearing_Rod_Adapter(Piston).stl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]
2026-08-09 new 3d print files push
    new 3d print files push
    [Big_motorSeat.stl, Big_motorSeat_brace.stl, CrankStand_BottomBrace.stl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]
2026-09-13 updated code + analysis
    Integrated Benjamini-Hochberg (BH) procedure to control the false discovery rate (FDR)
    [female_stats_mannwhitney_high performer_control_CLK_Out_w1.csv, female_stats_mannwhitney_high performer_control_Glaz_+_w3.csv, female_stats_mannwhitney_high pe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]
